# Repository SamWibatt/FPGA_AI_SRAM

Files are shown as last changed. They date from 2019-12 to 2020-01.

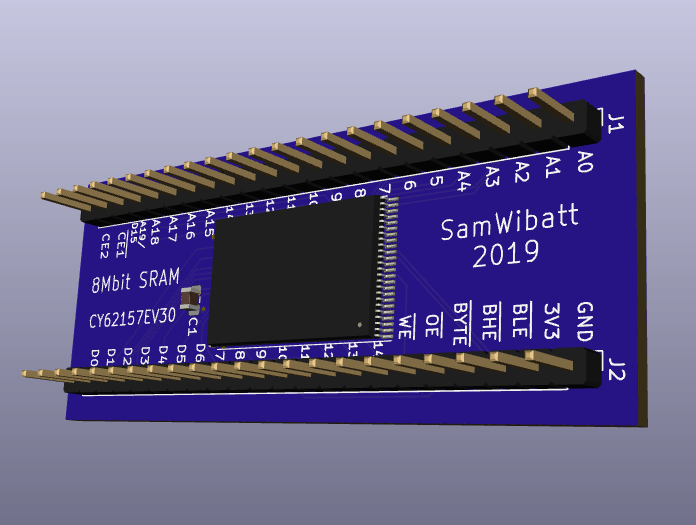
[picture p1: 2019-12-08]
KiCad/FPGA_AI_SRAM/FPGA_AI_SRAMv1-3d.png

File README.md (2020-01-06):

# FPGA_AI_SRAM
Preliminary part of AI acceleration with FPGAs, interfacing external memory for greater capacity.

Memory chips I will use for the experiments are the [Cypress Semiconductor Corp. CY62157EV30LL-45ZXIT 1Mx8 SRAM (pdf)](https://www.cypress.com/file/43021/download) and the [Cypress Semiconductor Corp S29AL008J55TFNR10 1Mx8 Flash (pdf)](https://www.cypress.com/file/216396/download). 

Chose these for cost and simplicity. They have the same footprint. The Flash has the advantages of costing $0.60 in 10-quantity from Digi-Key, so being good for TSOP soldering practice, as well as being able to retain data while unpowered. The SRAM is pricier at $2.93 in single quantity, so not bad. (On edit: that's a fluke, because the chips don't have a warranty... do they work? I don't know. I just ordered 10 more in hopes that they do. I reckon sooner or later I will just need to use DRAM. **FOR LATER REFERENCE WRT DRAM** [Lattice has a project related to it](http://www.latticesemi.com/en/Products/DesignSoftwareAndIP/IntellectualProperty/ReferenceDesigns/ReferenceDesigns01/FastPageModeDRAMController) though that appears to be just with one kind. Find docs about it in general; writing an sdram controller might not be so scary and looks like a good intermediate project. Perhaps https://pdfs.semanticscholar.org/d960/f5cc9782719dcfa780b4f4aea51b8f791c62.pdf, and let's move this discussion to a new project or at least the wiki.)

Their interface is easy to understand and they're kind of OK for speed. Speed in actual wall time is not the point of this exercise so much as speed in terms of clock cycles; I'm looking more for savings of complexity which will translated to savings in time once it can run on "real" hardware.

# Objective

The initial goal is to try accelerating some data structures such as red/black trees and running some old AI techniques like A* to get a feel for how well programmable logic can tighten them up.

Ultimately, I want to implement modern methods such as RNNs, but since I'm still working on tiny cheap eval boards it's unlikely I can do much - but I will look into it, and I will learn some useful things in this endeavor that will transfer (transfer learning LOL) I imagine I'm also going to have to pick up DSP for best results there.

OK so now got this project cloned onto makevm4, let's try a push from it. Not on the VPN, so I expect it to work.

Copied over some initial stuff like osresearch's makefile for their serial project, need hack up to do what I want AND DO WHATEVER I NEED TO DO TO SATISFY THE TERMS OF THEIR LICENSE!!!!!!!!!!!!

# Notes

**Release / tag v0.1 should be a good skeleton for future icestorm projects** But [the repository VerilogSkeleton](https://github.com/SamWibatt/VerilogSkeleton) should also be that and I will maintain it as such.

I will be keeping my usual stream of consciousness [notes in the repo wiki, qv](https://github.com/SamWibatt/FPGA_AI_SRAM/wiki).

Makefile, Makefile.icestorm, and upduino_v2.pcf are copied and modified from osresearch's code at https://github.com/osresearch/up5k licensed under GPL3

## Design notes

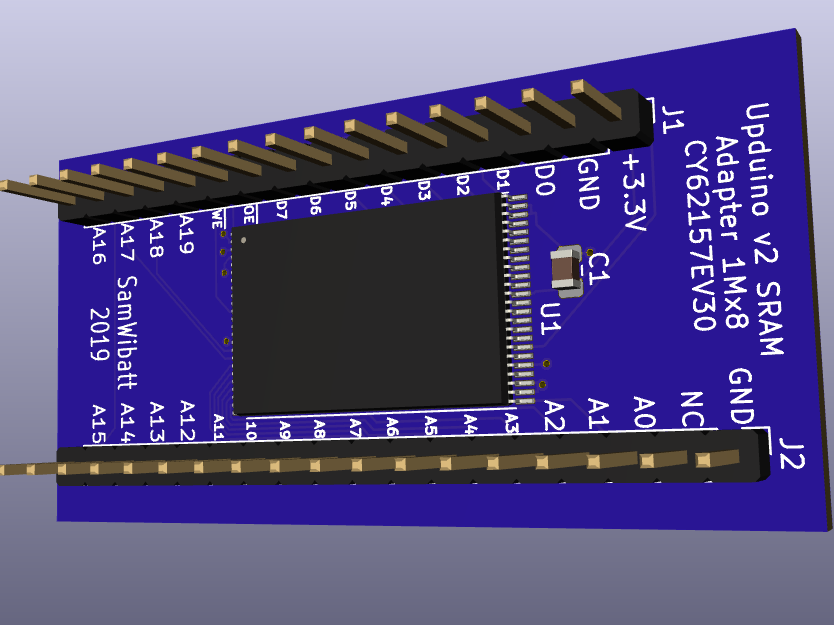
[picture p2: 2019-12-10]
KiCad/upduinov2.1-SRAM/upduinov2.1-SRAM-v1.png

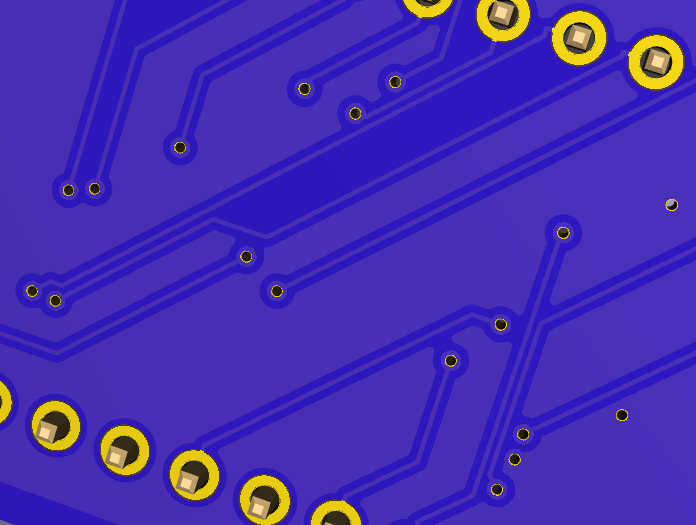
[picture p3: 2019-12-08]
KiCad/FPGA_AI_SRAM/FPGA_AI_SRAMv1-3d-back.png

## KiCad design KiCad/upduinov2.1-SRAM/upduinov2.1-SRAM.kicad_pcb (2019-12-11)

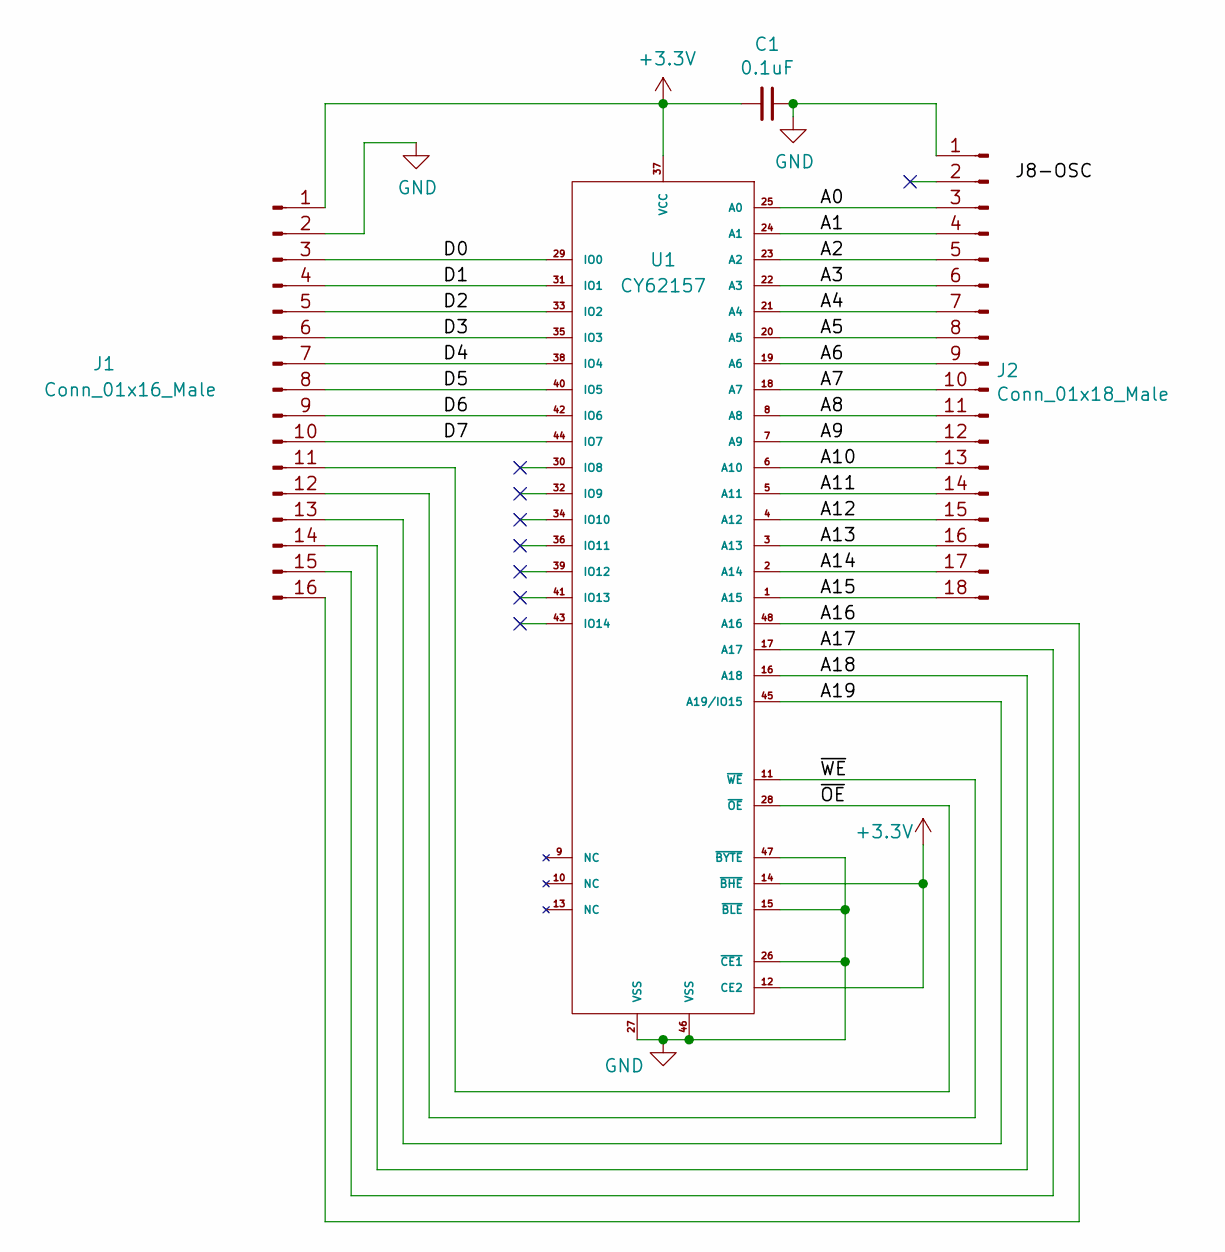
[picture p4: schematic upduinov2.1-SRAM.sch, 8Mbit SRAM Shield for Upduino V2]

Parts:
C1: 0.1uF; C_0805_2012Metric
J1: Conn_01x16_Male; PinHeader_1x16_P2.54mm_Vertical
J2: Conn_01x18_Male; PinHeader_1x18_P2.54mm_Vertical
U1: CY62157; TSOP-I-48_18.4x12mm_P0.5mm

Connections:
+3V3: C1.2, J1.1, U1.12 (CE2), U1.14 (~BHE), U1.37 (VCC)
/A0: J2.3, U1.25 (A0)
/A1: J2.4, U1.24 (A1)
/A2: J2.5, U1.23 (A2)
/A3: J2.6, U1.22 (A3)
/A4: J2.7, U1.21 (A4)
/A5: J2.8, U1.20 (A5)
/A6: J2.9, U1.19 (A6)
/A7: J2.10, U1.18 (A7)
/A8: J2.11, U1.8 (A8)
/A9: J2.12, U1.7 (A9)
/A10: J2.13, U1.6 (A10)
/A11: J2.14, U1.5 (A11)
/A12: J2.15, U1.4 (A12)
/A13: J2.16, U1.3 (A13)
/A14: J2.17, U1.2 (A14)
/A15: J2.18, U1.1 (A15)
/A16: J1.16, U1.48 (A16)
/A17: J1.15, U1.17 (A17)
/A18: J1.14, U1.16 (A18)
/A19: J1.13, U1.45 (A19/IO15)
/D0: J1.3, U1.29 (IO0)
/D1: J1.4, U1.31 (IO1)
/D2: J1.5, U1.33 (IO2)
/D3: J1.6, U1.35 (IO3)
/D4: J1.7, U1.38 (IO4)
/D5: J1.8, U1.40 (IO5)
/D6: J1.9, U1.42 (IO6)
/D7: J1.10, U1.44 (IO7)
/~OE: J1.11, U1.28 (~OE)
/~WE: J1.12, U1.11 (~WE)
GND: C1.1, J1.2, J2.1, U1.15 (~BLE), U1.26 (~CE1), U1.27 (VSS), U1.46 (VSS), U1.47 (~BYTE)

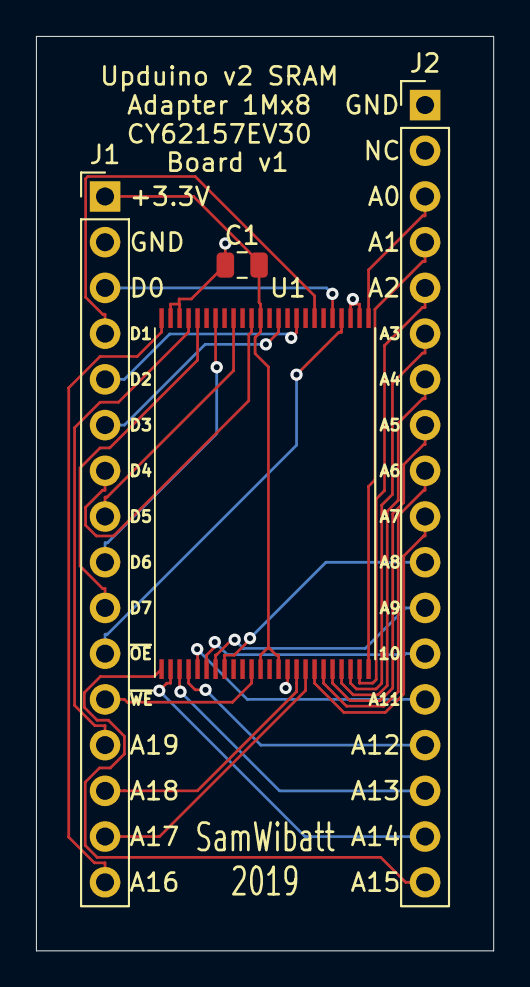
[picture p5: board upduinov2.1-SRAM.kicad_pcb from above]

Board: 2 copper layers, 25.4 x 50.8 mm, 4 parts (0 on the bottom side), 32 nets.

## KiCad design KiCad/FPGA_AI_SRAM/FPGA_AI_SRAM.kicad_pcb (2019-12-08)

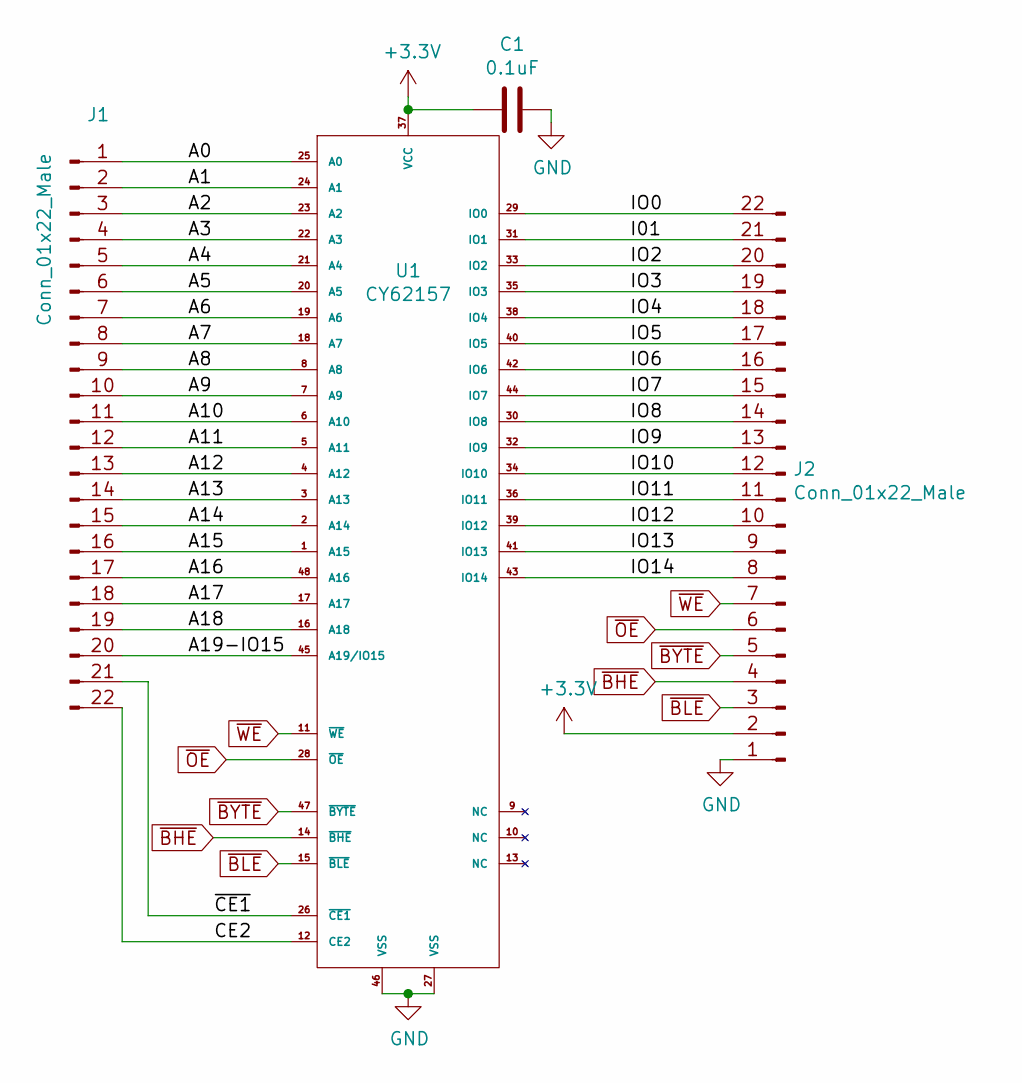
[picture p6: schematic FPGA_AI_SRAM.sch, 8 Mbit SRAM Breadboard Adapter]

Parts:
C1: 0.1uF; C_0805_2012Metric
J1, J2: Conn_01x22_Male; PinHeader_1x22_P2.54mm_Vertical
U1: CY62157; TSOP-I-48_18.4x12mm_P0.5mm

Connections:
+3V3: C1.2, J2.2, U1.37 (VCC)
/A0: J1.1, U1.25 (A0)
/A1: J1.2, U1.24 (A1)
/A2: J1.3, U1.23 (A2)
/A3: J1.4, U1.22 (A3)
/A4: J1.5, U1.21 (A4)
/A5: J1.6, U1.20 (A5)
/A6: J1.7, U1.19 (A6)
/A7: J1.8, U1.18 (A7)
/A8: J1.9, U1.8 (A8)
/A9: J1.10, U1.7 (A9)
/A10: J1.11, U1.6 (A10)
/A11: J1.12, U1.5 (A11)
/A12: J1.13, U1.4 (A12)
/A13: J1.14, U1.3 (A13)
/A14: J1.15, U1.2 (A14)
/A15: J1.16, U1.1 (A15)
/A16: J1.17, U1.48 (A16)
/A17: J1.18, U1.17 (A17)
/A18: J1.19, U1.16 (A18)
/A19-IO15: J1.20, U1.45 (A19/IO15)
/CE2: J1.22, U1.12 (CE2)
/I01: J2.21, U1.31 (IO1)
/IO0: J2.22, U1.29 (IO0)
/IO2: J2.20, U1.33 (IO2)
/IO3: J2.19, U1.35 (IO3)
/IO4: J2.18, U1.38 (IO4)
/IO5: J2.17, U1.40 (IO5)
/IO6: J2.16, U1.42 (IO6)
/IO7: J2.15, U1.44 (IO7)
/IO8: J2.14, U1.30 (IO8)
/IO9: J2.13, U1.32 (IO9)
/IO10: J2.12, U1.34 (IO10)
/IO11: J2.11, U1.36 (IO11)
/IO12: J2.10, U1.39 (IO12)
/IO13: J2.9, U1.41 (IO13)
/IO14: J2.8, U1.43 (IO14)
/~CE1: J1.21, U1.26 (~CE1)
GND: C1.1, J2.1, U1.27 (VSS), U1.46 (VSS)
~BHE: J2.4, U1.14 (~BHE)
~BLE: J2.3, U1.15 (~BLE)
~BYTE: J2.5, U1.47 (~BYTE)
~OE: J2.6, U1.28 (~OE)
~WE: J2.7, U1.11 (~WE)

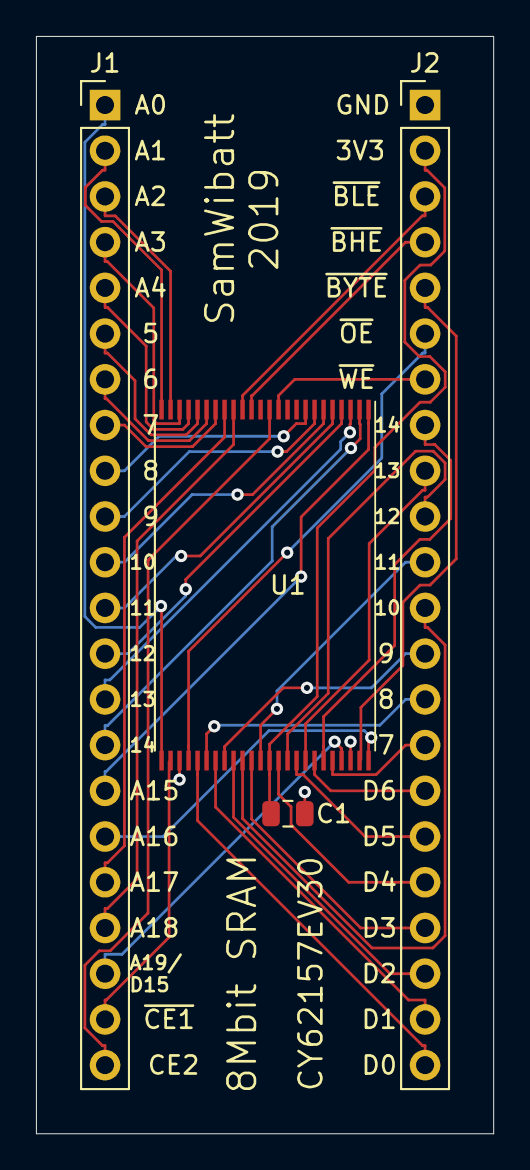
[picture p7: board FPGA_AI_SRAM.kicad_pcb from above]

Board: 2 copper layers, 25.4 x 61.0 mm, 4 parts (0 on the bottom side), 44 nets.

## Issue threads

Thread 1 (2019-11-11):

Make SRAM / FLASH board

SamWibatt, 2019-11-11:
I own some TSOP-48 SRAM chips, CY62157EV30, and some Flash chips S29AL008J with the same footprint because the flashers are much cheaper and I wanted something to practice soldering on.

I fear opening the packages because they will get moisture on them and need baking and eep

For this issue, solder a flash or sram to one of my tsop adapters and break it out to be usable by an FPGA dev board.

SamWibatt, 2019-11-13:
Tried a drag solder! Almost worked. See discussion here https://www.instagram.com/p/B4wK8SDDiKB/ and https://www.youtube.com/watch?v=wUyetZ5RtPs - embarrassingly, didn't think to watch vid tutorials.

Will try another one with a flash chip, and if that works, do one with an sram (or even both!)

SamWibatt, 2019-11-16:
K so I believe I have correctly soldered a flash chip! I shall try to do an sram too, and hope that the chips don't all go soggy before I use them. I suppose I could just solder all the SRAMs to breakouts and if I need more, they're not THAT spendy.

SamWibatt, 2019-12-07:
Closing bc I seem to have the same issue 3 times, and this one I have at least soldered a chip successfully now. I will call it good.

Closed 2019-12-07.

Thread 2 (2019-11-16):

make a "paddle" for breakout board SRAM or flash

SamWibatt, 2019-11-16:
1. Perhaps the thing to make is a "paddle" that adapts the TSOP breakout to a breadboard connector. That is, put laigs on the breakout, then make the paddle with female headers that match those, and lead to two rows of pins that are breadboardable.
        1. Could do like 20 pins along one side for the address and ... then however many on the other side for the data and control signals and power? That'd be lopsided but thematically nice

Closed 2020-03-01.

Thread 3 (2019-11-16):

Design a breadboard adapter for SRAM/flash and have fabbed

SamWibatt, 2019-11-16:
OshPark, natch, got to have that mad rad purple board. Simple design, just a 48TSOP and a bunch of pins, no need to adapt a breakout board. That would be a fun way to try out the service. Don't forget the decoupling capacitor!

SamWibatt, 2019-11-17:
How about making them stackable and using a dual inverter with jumpers or switches - as I wrote in notes,
Oh YEAH I also had this idea about the SRAM / flash breakout that I could add an inverter chip, like the old LS04 or whatever it was, and now they have the teeny https://www.digikey.com/product-detail/en/nexperia-usa-inc/74HC2G04GV125/1727-6914-1-ND/2814153 which only has 2 inverters – may need more – and some jumpers or dip swicths, and the idea was that you could move the jumpers or dip swicths or whatever to fiddle the logic on the chip-enable pins, so you could then stack a bunch of these and the CE pins would work as intended, extra address lines, yes? So since there are two chip enables, I guess you could get 4 chips stacked up, could do like 3 SRAMs and a Flash for 4MB, 1MB of which is (mostly) read-only, or at least write-seldom and persistent.

SamWibatt, 2019-11-17:
Then I'd have stackable "shields" for an FPGA thing
Could also put a couple rows of connectors on there so it could work with either the icestick OR the upduino, and consider a footprint for tinyfpga too

SamWibatt, 2019-11-17:
Their cohorts all gleaming in purple and gold. OH HEY THAT WAS WRITTEN BY LORD BYRON whose daughter was Lady Ada herownself

SamWibatt, 2019-11-17:
Started a digikey BOM for this, SRAM-Flash Shield, with 10x74HC2G04 in it

Closed 2020-03-01.

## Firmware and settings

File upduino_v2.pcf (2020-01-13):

# The LED pins are using the current controlled outputs
# and are negative logic (write a 0 to turn on).
set_io led_r	41
set_io led_g	39
set_io led_b	40

# FTDI chip, which sort of works
set_io -nowarn serial_txd 14 # FPGA transmit to USB
set_io -nowarn serial_rxd 15 # FPGA receive from USB
set_io -nowarn spi_cs 16 # Drive high to ensure that the SPI flash is disabled
# set_io serial_rts_n 14  # no?
# set_io serial_dtr_n 16  # no?

# Normal GPIO pins, left side (when looking at top side of upduino2
# with usb connector at top)
# settings from sram board for upduino2!
set_io io_data[0] 23
set_io io_data[1] 25
set_io io_data[2] 26
set_io io_data[3] 27
set_io io_data[4] 32
set_io io_data[5] 35
set_io io_data[6] 31
set_io io_data[7] 37
set_io o_n_oe 34
set_io o_n_we 43
set_io o_addr[19] 36
set_io o_addr[18] 42
set_io o_addr[17] 38
set_io o_addr[16] 28

# Normal GPIO pins, right side
set_io o_addr[0]  12
set_io o_addr[1]  21
set_io o_addr[2]  13
set_io o_addr[3]  19
set_io o_addr[4]  18
set_io o_addr[5]  11
set_io o_addr[6]  9
set_io o_addr[7]  6
set_io o_addr[8]  44
set_io o_addr[9]  4
set_io o_addr[10] 3
set_io o_addr[11] 48
set_io o_addr[12] 45
set_io o_addr[13] 47
set_io o_addr[14] 46
set_io o_addr[15] 2

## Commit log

2019-12-07 added KiCad project and sram part
    [FPGA_AI_SRAM.kicad_pcb, FPGA_AI_SRAM.sch]
2019-12-07 kicad template for OSH Park hopework
    [FPGA_AI_SRAM.sch, OSHPark_2Layer.kicad_pcb, OSHPark_2Layer.sch]
2019-12-07 paddle schematic done
    [FPGA_AI_SRAM.kicad_pcb, FPGA_AI_SRAM.sch]
2019-12-08 possible pcb v1
    [FPGA_AI_SRAM.dsn, FPGA_AI_SRAM.kicad_pcb]
2019-12-08 better board with hand routed decoupler
    [FPGA_AI_SRAM.dsn, FPGA_AI_SRAM.kicad_pcb]
2019-12-08 better board fully autorouted
    [FPGA_AI_SRAM.dsn, FPGA_AI_SRAM.kicad_pcb]
2019-12-08 improved silkscreen, added 3d img
    [FPGA_AI_SRAM.kicad_pcb]
2019-12-08 added net names
    [FPGA_AI_SRAM.kicad_pcb, FPGA_AI_SRAM.sch]
2019-12-09 added blank upduino kicad
    [blank-upduinov2.1.kicad_pcb]
2019-12-09 made upduinov2.1-sram kicad project w oshpark settings
    [upduinov2.1-SRAM.kicad_pcb]
2019-12-09 fixed pin number on upd-SRAM pcb
    [upduinov2.1-SRAM.kicad_pcb]
2019-12-10 New Upduino shield
    [upduinov2.1-SRAM.kicad_pcb, upduinov2.1-SRAM.sch]
2019-12-10 updv2 pcb v1 w handroute decoupler
    [upduinov2.1-SRAM.dsn, upduinov2.1-SRAM.kicad_pcb, upduinov2.1-SRAM.sch]
2019-12-10 cropped pcb img
2019-12-11 added board version number
    [upduinov2.1-SRAM.kicad_pcb]
2020-01-13 sram module stubbed, test doesn't compile
    [upduino_v2.pcf]
2020-02-14 first cut at config includes
